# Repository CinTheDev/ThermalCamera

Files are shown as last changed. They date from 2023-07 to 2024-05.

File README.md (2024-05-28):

# Thermal Camera

A project for the Raspberry Pi, where a thermal camera is connected to the Raspi, which save or display pictures on a screen.

## Raspberry Pi image setup

### Initial setup

Following steps have been taken for the Raspberry Pi setup:

- Install Raspberry OS x32 on the SD card
- Setup install
- Country & Language: German
- Username: thermal-camera
- Password: thermal-camera
- Connect to WIFI
- Finish setup & Restart
- Enable ssh via systemctl

Now the Raspi can be accessed via `ssh thermal-camera@raspberrypi`

At this point, there is no need for an external keyboard and monitor anymore, the Raspi just needs to be powered and in reach of the configured WIFI.

Optional:

- Add personal public ssh key for easy access via ssh
- Install eog for viewing image files via ssh

### Peripheral setup

Later, when enabling the I2C peripheral:

- `sudo raspi-config`
- -> Interfacing Options
- -> I2C
- -> "Yes" to enable
- -> Finish

Restart so I2C can be activated.

Lastly, increase the speed of the I2C peripheral for images to be read much quicker:

- `sudo nano /boot/config.txt`
- Look for `dtparam=i2c_arm=on`
- Append `,i2c_arm_baudrate=400000` or whatever speed should be used
- Save

And restart again.

### Display setup

In order to use the display, some things still have to be configured.

<https://www.waveshare.com/wiki/3.5inch_RPi_LCD_(A)#Getting_Started>

Follow the first part of the guide with the driver installaion, skip the rest.

If the touchscreen axes are "inverted" in some way after reboot, you must edit `/usr/share/X11/xorg.conf.d/99-callibration.conf` and change "SwapAxes" to "0" (or to "1" if it's already 0)

Now the touchscreen should behave properly.

#### Increase Display framerate

If the default framerate is too slow:

- `sudo nano /boot/config.txt`
- Look for `dtoverlay=waveshare35a` and append `:speed=20000000,fps=30` or other desired values
- Save and restart

## Development setup

On our working machine, we have to make sure we can cross compile the program and upload it to the raspi.

We first have to add the correct Rust toolchain:

`rustup target add armv7-unknown-linux-gnueabihf`

We will use cargo cross for compiling. Install cross with `cargo install cross`

Additionally, we will use `podman` for cross, you can use docker instead, but it's kinda a chore to deal with root priviledges. Install podman with `sudo apt install podman`.

## Hardware setup & Used pins

### MLX Thermal Camera

The MLX module is connected to Raspberry Pi GPIO in the following fashion:

- [Camera Pin] > [Raspi Pin]
- VIN > 5V (Pin 2)
- GND > Ground (Any Pin equal or above Pin 30)
- SCL > Pin 3 (I2C SCL)
- SDA > Pin 2 (I2C SDA)

### Display Pins

Since some Pins are used by the MLX, we cannot put the Display directly on the Raspberry Pi, we have to manually connect the pins with jumper wires.

Also, the display, by documentation, occupies every power pin on the raspi. This is a problem since the MLX needs one power pin for itself. I have discovered that keeping **Pin 2 disconnected** won't affect the display. That way we have a free power pin for the MLX.

Use the display guide mentioned above in Display Setup to connect the relevant pins. The pins are listed on the bottom of the page.

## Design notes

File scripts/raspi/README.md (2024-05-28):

# Thermal Camera Raspberry Pi configuration

This directory contains scripts to fully configure a Raspberry Pi to run thermal-camera on startup

## Setup

Do the following before running any scripts inside here:

- Prepare a new Raspbian OS lite x32 sd card; if possible, do the following steps inside the raspberry pi imager
- **IMPORTANT: Do not choose anything newer than Raspbian Bullseye, display won't work otherwise!**
- (It's recommended to set the hostname to something other than raspberrypi)
- Make sure to create a user 'pi' with sudo rights; this will serve as the administrative user
- Connect to the internet either over wifi (recommended) or over ethernet
- (Turn on ssh)

## Installation

- Login as pi either over ssh or directly
- Copy this directory to /home/pi
- Set executable flag for run.sh
- Execute run.sh

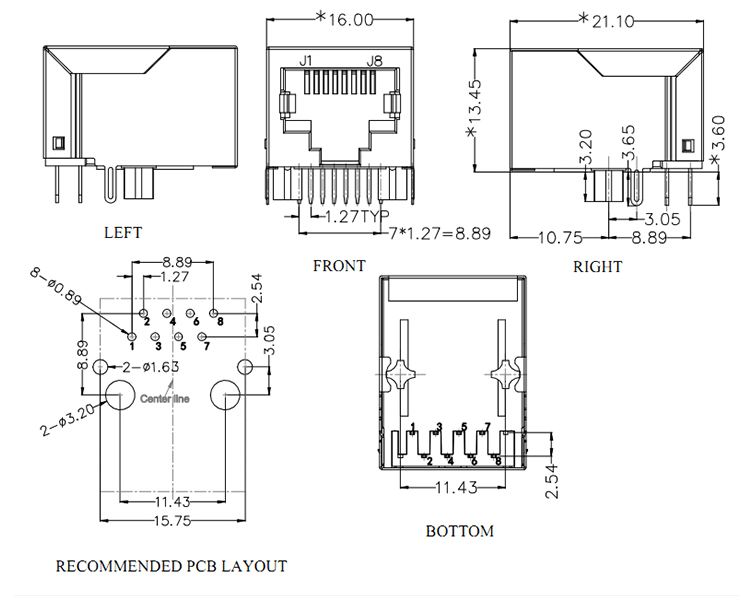
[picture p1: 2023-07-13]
Datasheets/Peripherals/Ethernet.png

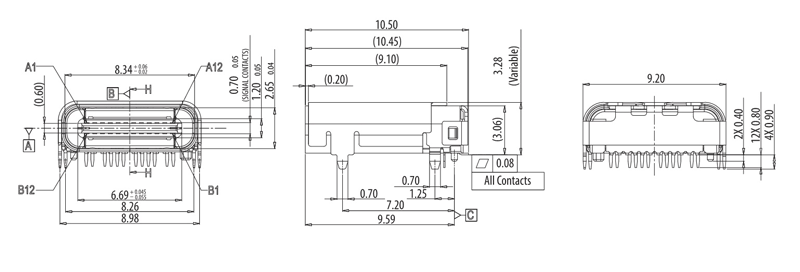
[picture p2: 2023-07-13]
Datasheets/Peripherals/USB_C_Female.png

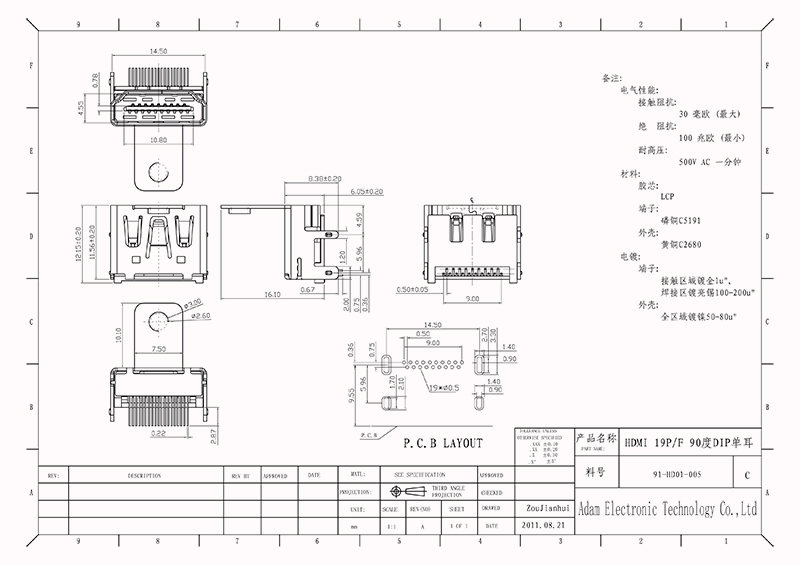
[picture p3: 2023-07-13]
Datasheets/Peripherals/HDMI_Mini_Female.jpg

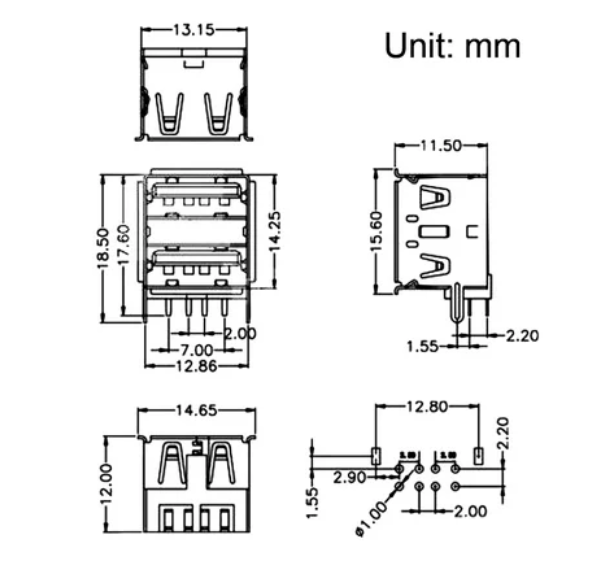
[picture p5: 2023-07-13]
Datasheets/Peripherals/USB_A_Female.png

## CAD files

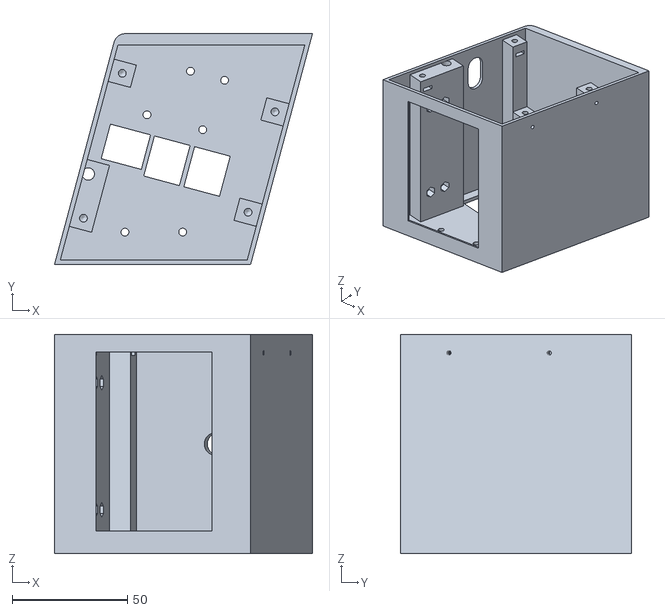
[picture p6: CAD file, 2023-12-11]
CAD_CaseV2/Export/Casing.stl
111.8 x 100.0 x 95.0

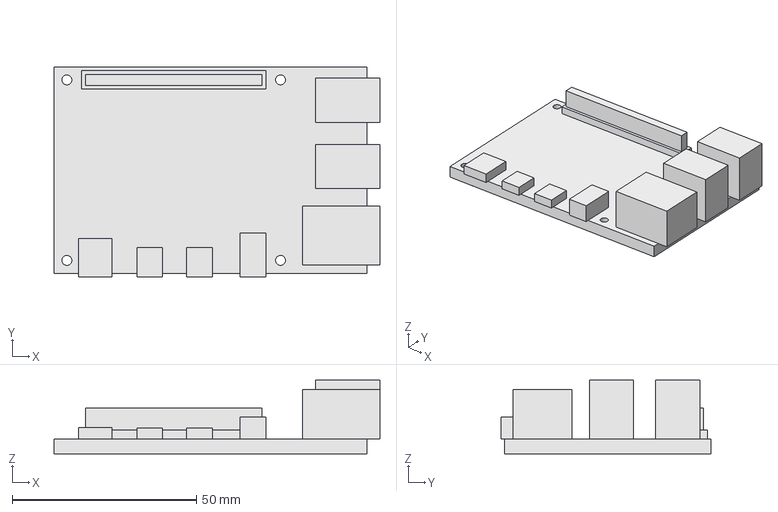
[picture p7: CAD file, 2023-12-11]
CAD_CaseV2/Parts/Raspberrypi4B.FCStd
88.5 x 57.0 x 20.0 mm

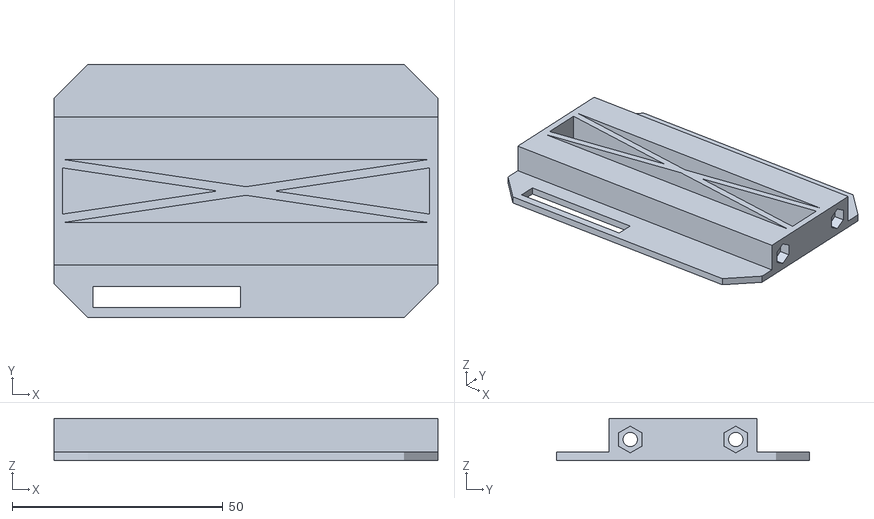
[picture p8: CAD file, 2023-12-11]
CAD_CaseV2/Export/Support_Display.stl
91.0 x 60.0 x 10.0

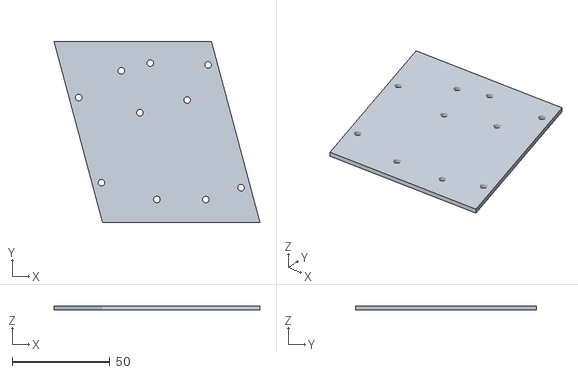
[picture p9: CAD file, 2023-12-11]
CAD_CaseV2/Export/Lid.stl
105.3 x 92.5 x 2.00

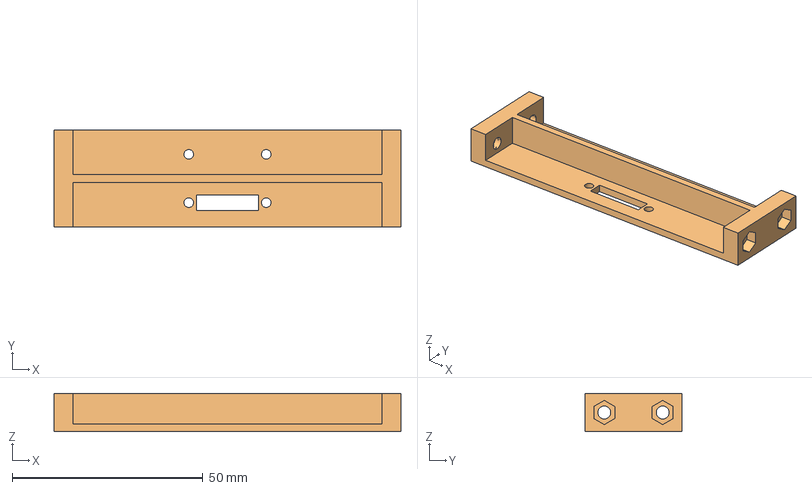
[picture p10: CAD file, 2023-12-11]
CAD_CaseV2/Parts/Support_MLX.FCStd
91.0 x 25.3 x 10.0 mm
Body (Meshed)

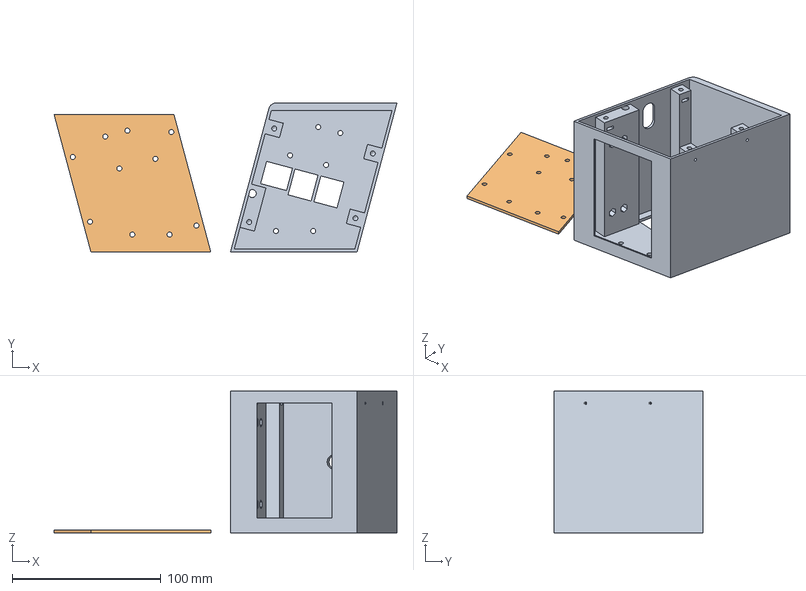
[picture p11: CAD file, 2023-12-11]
CAD_CaseV2/Export/CaseV2.3mf
230.3 x 100.1 x 95.0 mm
Casing.stl
Lid.stl

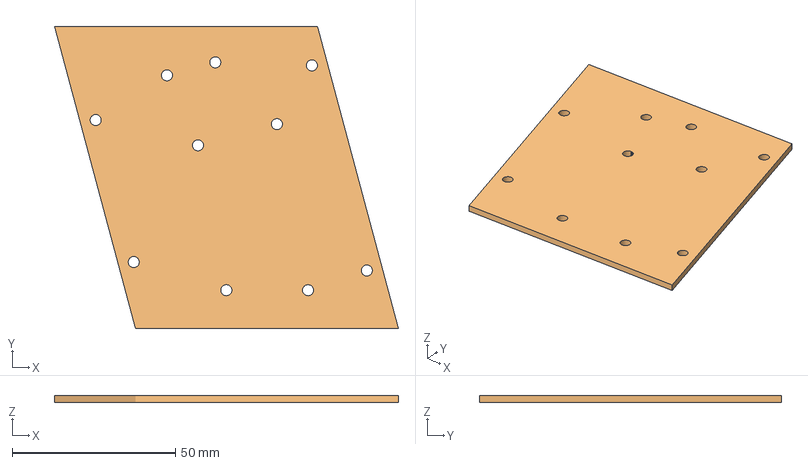
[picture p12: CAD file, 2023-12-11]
CAD_CaseV2/Parts/Casing_Lid_2.FCStd
105.3 x 92.5 x 2.00 mm
Körper
Körper (Meshed)

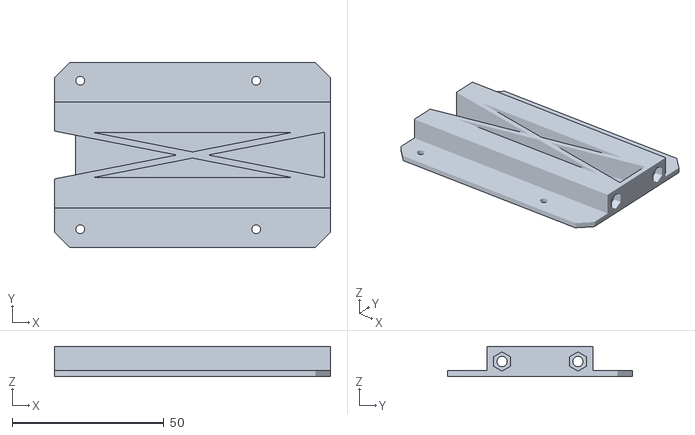
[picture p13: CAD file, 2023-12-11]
CAD_CaseV2/Export/Support_Raspi.stl
91.0 x 61.0 x 10.0

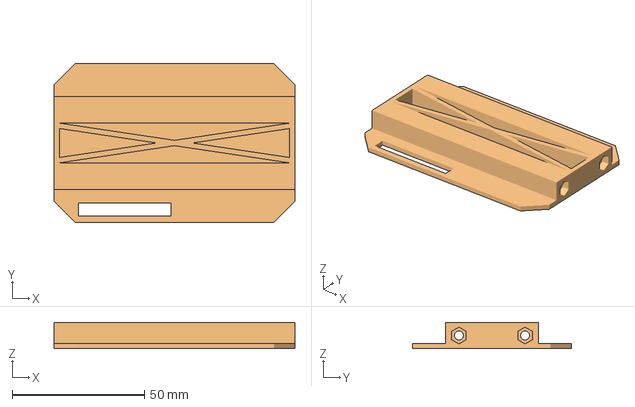
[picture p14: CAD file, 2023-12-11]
CAD_CaseV2/Parts/Support_Display_new.FCStd
91.0 x 60.0 x 10.0 mm
Körper
Körper (Meshed)

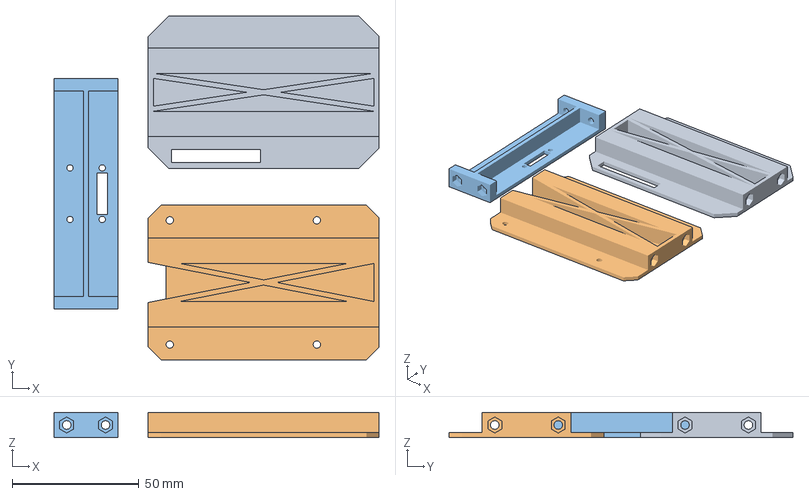
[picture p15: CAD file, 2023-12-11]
CAD_CaseV2/Export/Supports_V2.3mf
128.2 x 135.5 x 10.0 mm
Support_Display.stl
Support_Raspi.stl
Support_MLX.stl

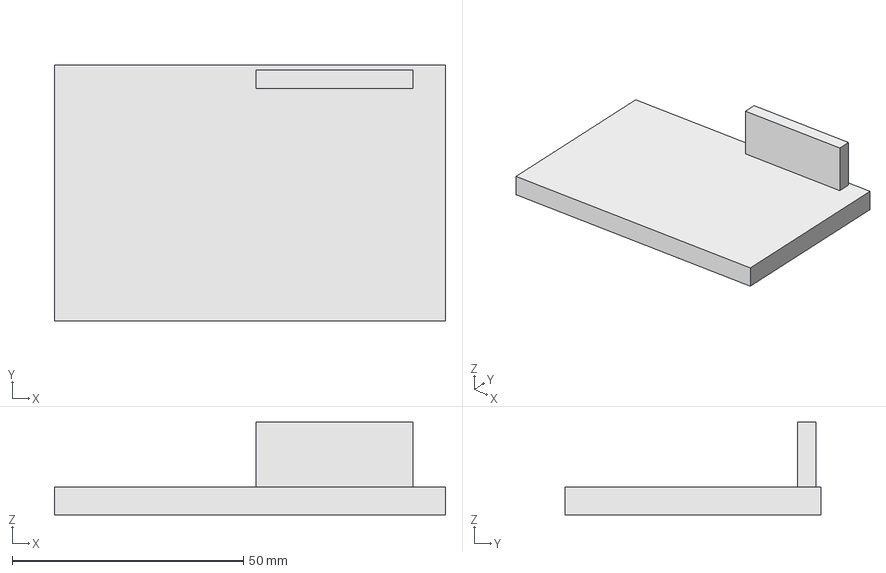
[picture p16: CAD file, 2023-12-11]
CAD_CaseV2/Parts/Display_Berrybase.FCStd
84.5 x 55.3 x 20.0 mm

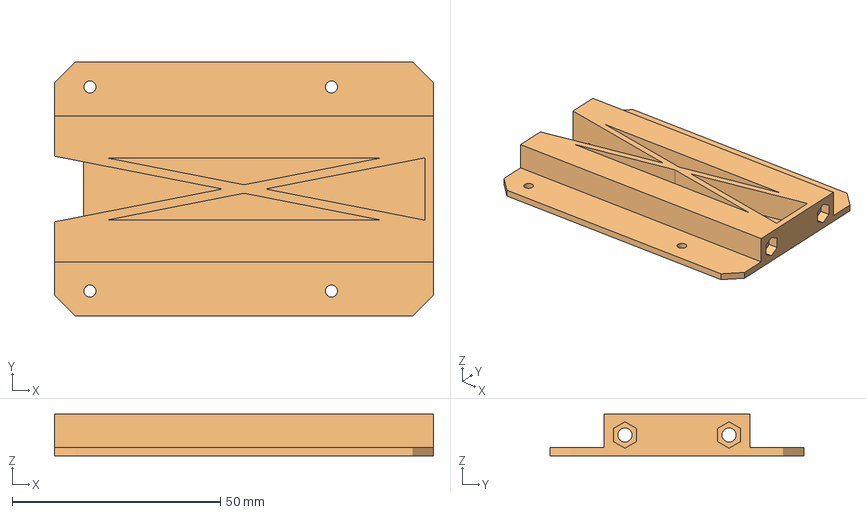
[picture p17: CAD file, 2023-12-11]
CAD_CaseV2/Parts/Support_Raspi_new.FCStd
91.0 x 61.0 x 10.0 mm
Körper
Körper (Meshed)

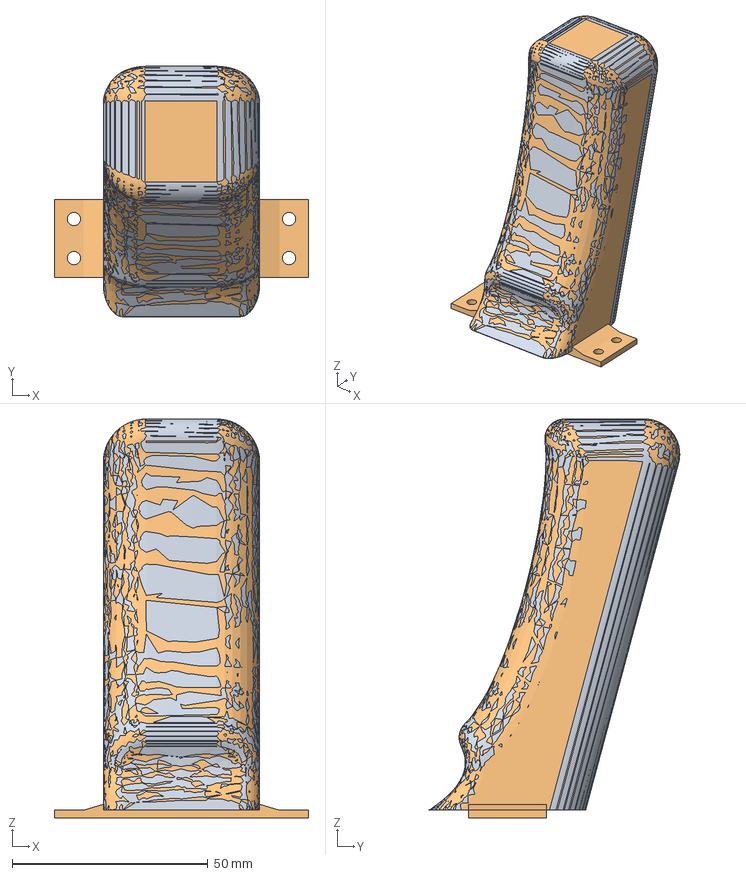
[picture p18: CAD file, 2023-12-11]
CAD_CaseV2/Parts/Handgrip.FCStd
65.0 x 64.1 x 102.0 mm
Körper
Körper (Meshed)

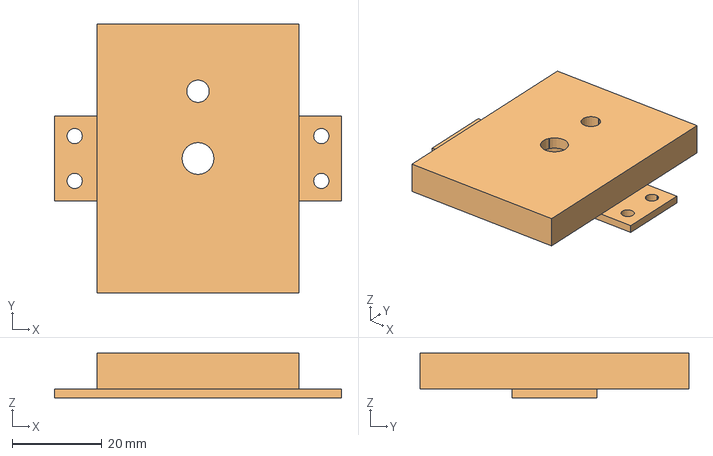
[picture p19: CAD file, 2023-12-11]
CAD_CaseV2/Parts/Tripod_Connector.FCStd
64.0 x 60.0 x 10.0 mm
Körper
Körper (Meshed)

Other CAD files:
CAD_CaseV2/CaseV2_Assembly.FCStd
CAD_CaseV2/Parts/Casing2.FCStd
CAD_CaseV2/Parts/MLX90640.FCStd
CAD_CaseV2/Export/Handgrip.3mf
CAD_CaseV2/Export/Handgrip.stl
CAD_CaseV2/Export/Support_MLX.stl
CAD_CaseV2/Export/Tripod_Connector.3mf
CAD_CaseV2/Export/Tripod_Connector.stl

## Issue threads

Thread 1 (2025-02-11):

Equivalent to set i2c frequency like  busio.I2C(board.SCL, board.SDA, frequency=frequency)

UlmerMan, 2025-02-11:
Description:

I'm looking for a way to set the I2C frequency in this crate, similar to how it can be done in CircuitPython using busio.I2C with the frequency parameter, like this:

```
import board
import busio

i2c = busio.I2C(board.SCL, board.SDA, frequency=100_000)
```

In particular, I'd like to know:

 -   Is there a way to specify the I2C frequency directly when initializing the I2C bus?

It would be helpful for applications where controlling the bus speed is essential (e.g., for devices with stricter timing requirements).

CinTheDev, 2025-02-11:
Unfortunately, there's no way right now to do this software wise. The crate uses `rppal` for utilizing the raspi I2C hardware.

Though, you can change the raspi configuration in `/boot/firmware/config.txt` to adjust the speed. The rppal documentation says the same:

> By default, the I2C bus clock speed is set to 100 kHz. Transferring 1 bit takes 1 clock cycle. You can change the transfer rate by adding dtparam=i2c_arm_baudrate=X to /boot/firmware/config.txt, where X should be replaced with the clock frequency in hertz (Hz). Remember to reboot the Raspberry Pi afterwards.

So, in your example you would add `dtparam=i2c_arm_baudrate=100000` to `/boot/firmware/config.txt`. (If it's there already, edit it)

UlmerMan, 2025-02-12:
Thank you for the fast answer and your amazing work

Closed 2025-02-12.

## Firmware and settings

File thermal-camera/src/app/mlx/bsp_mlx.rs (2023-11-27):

use rppal::i2c::I2c;
use std::sync::Mutex;
use lazy_static::lazy_static;

mod mlx_eeprom;

use super::PIXEL_COUNT;

const CAM_ADDR: u8 = 0x33;

pub const REGISTER_STATUS: u16 = 0x8000;
pub const REGISTER_CTRL: u16 = 0x800D;
pub const ADDRESS_RAM: u16 = 0x0400;

lazy_static! {
    static ref I2C_MUTEX: Mutex<u32> = Mutex::new(0);
}

pub fn write(address: u16, data: u16) -> Result<(), String> {
    let _i2c_lock = I2C_MUTEX.lock().unwrap();

    let i2c_p_response = I2c::new();

    if i2c_p_response.is_err() {
        return Err(format!("I2C Peripheral failure\n{}", i2c_p_response.unwrap_err()));
    }

    let mut i2c = i2c_p_response.unwrap();
    i2c.set_slave_address(CAM_ADDR as u16).unwrap();

    let mut buffer: [u8; 4] = [0x00; 4];
    buffer[0..2].copy_from_slice(&address.to_be_bytes());
    buffer[2..4].copy_from_slice(&data.to_be_bytes());
    
    let i2c_write_response = i2c.write(&buffer);
    if i2c_write_response.is_err() {
        return Err(format!("I2C Write failure\n{}", i2c_write_response.unwrap_err()));
    }

    return Ok(());
}

pub fn read(address: u16, read_buffer: &mut [u8]) -> Result<(), String> {
    let _i2c_lock = I2C_MUTEX.lock().unwrap();

    let i2c_p_response = I2c::new();

    if i2c_p_response.is_err() {
        return Err(format!("I2C Peripheral failure\n{}", i2c_p_response.unwrap_err()));
    }

    let mut i2c = i2c_p_response.unwrap();
    i2c.set_slave_address(CAM_ADDR as u16).unwrap();

    let mut write_buffer: [u8; 2] = [0x00; 2];
    write_buffer.copy_from_slice(&address.to_be_bytes());

    let i2c_read_response = i2c.write_read(&write_buffer, read_buffer);
    if i2c_read_response.is_err() {
        return Err(format!("I2C Read failure\n{}", i2c_read_response.unwrap_err()));
    }

    return Ok(());
}

pub fn read_value(address: u16) -> Result<u16, String> {
    let mut read_buffer: [u8; 2] = [0x00; 2];
    let read_response = read(address, &mut read_buffer);

    if read_response.is_err() {
        return Err(read_response.unwrap_err());
    }

    return Ok(u16::from_be_bytes(read_buffer));
}

pub fn evaluate_image(pix_data: [u16; PIXEL_COUNT]) -> Result<[f32; PIXEL_COUNT], String> {
    return mlx_eeprom::evaluate(pix_data);
}

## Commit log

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2023-05-10 Fully replace old i2c code
    [bsp_mlx.rs]
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2023-05-11 Replace eeprom_raw with whole data block
    [bsp_mlx.rs]
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2023-05-14 Fix all mistakes and save temperature output
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2023-05-24 Fix t clamping
2023-06-02 Change target because of linking issues
    Currently the rust compiler is complaining about failed linking,
    and if it does succeed the program won't run on the raspy because of issues with glibc.
    I'll look into that now.
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2023-06-21 Add new FreeCAD project
    [Case_Assembly.FCStd]
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2023-06-21 Create base of Raspberrypi model
    [Raspberrypi4B.FCStd]
2023-06-21 Make spreadsheet and replace most numbers
    [Case_Assembly.FCStd, Raspberrypi4B.FCStd]
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2023-06-21 Replace raspi spreadsheet expressions
    Replace all Case_Assembly#Spreadsheet... with <<Case_Assembly>>#<<Spreadheet>>...
    [Raspberrypi4B.FCStd]
2023-06-21 Update mlx pcb factor to represent an inch
    [Case_Assembly.FCStd, MLX90640.FCStd, Raspberrypi4B.FCStd]
2023-06-26 Add berrybase display CAD and empty Casing left file
    [Case_Assembly.FCStd, Casing_Left.FCStd, Display_Berrybase.FCStd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]
2023-06-26 Add basic shape for casing
    [Casing_Left.FCStd]
2023-06-26 Create rough outline of casing fron side
    [Casing_Left.FCStd]
2023-06-26 Add bspline for handgrip
    [Casing_Left.FCStd]
2023-06-26 Convert all units to mm
    [Case_Assembly.FCStd, Casing_Left.FCStd, Display_Berrybase.FCStd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]
2023-06-26 Add second depth for bspline
    [Casing_Left.FCStd]
2023-06-26 Edit main case shape end remove first sketch
    [Casing_Left.FCStd]
2023-06-26 Pocket the handgrip into shape
    [Casing_Left.FCStd]
2023-06-26 Add basic pocket to hollow out casing
    [Casing_Left.FCStd]
2023-06-27 Remove Casing_left, Replace with Casing_middle
    [Casing_Left.FCStd, Casing_Middle.FCStd]
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2023-06-27 Add hole in casing for mlx camera
    [Casing_Left.FCStd, Casing_Middle.FCStd]
2023-06-28 Add Casing_Right as well
    [Casing_Left.FCStd, Casing_Right.FCStd]
2023-06-28 Fix Casing_Left orientation
    [Casing_Left.FCStd]
2023-06-28 Start adding beams to Casing_Left
    [Casing_Left.FCStd, Casing_Middle.FCStd, Casing_Right.FCStd]
2023-06-28 Move mlx spreadsheet values to mlx file
    [Case_Assembly.FCStd, MLX90640.FCStd]
2023-06-28 Add Case_Middle to main assembly
    [Case_Assembly.FCStd, Casing_Middle.FCStd, MLX90640.FCStd]
2023-06-28 Add more beams to Casing_left
    [Case_Assembly.FCStd, Casing_Left.FCStd, Casing_Middle.FCStd]
2023-06-28 Add screwholes to casing_left
    [Casing_Left.FCStd]
2023-06-28 Add screwholes to Casing_Middle and add Casing_Left to assembly
    [Case_Assembly.FCStd, Casing_Left.FCStd, Casing_Middle.FCStd]
2023-06-28 Fix various errors which popped up
    [Case_Assembly.FCStd, Casing_Left.FCStd]
2023-06-28 Shorten beam length to correct size
    [Case_Assembly.FCStd, Casing_Left.FCStd]
2023-06-28 Fix Casing_Left
    [Case_Assembly.FCStd, Casing_Left.FCStd, Casing_Middle.FCStd]
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2023-06-30 Add carrier beam for mlx
    [Case_Assembly.FCStd, Casing_Left.FCStd, Casing_Middle.FCStd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]
2023-06-30 Add mlx carrier to main assembly
    [Case_Assembly.FCStd, Casing_Left.FCStd, Casing_Middle.FCStd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]
2023-06-30 Add mlx camera to main assembly
    [Case_Assembly.FCStd, Casing_Left.FCStd, Casing_Middle.FCStd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]
2023-06-30 Add holes to Case_Right as well
    [Case_Assembly.FCStd, Casing_Left.FCStd, Casing_Middle.FCStd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]
2023-07-03 Add own spreadsheets to Raspberrypi4B and Display_Berrybase
    [Case_Assembly.FCStd, Casing_Left.FCStd, Casing_Right.FCStd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]
2023-07-03 Replace raspi fixed lengths with spreadsheet values
    [Raspberrypi4B.FCStd]
2023-07-03 Add carrier for raspberrypi
    [Raspberrypi4B.FCStd, Support_Raspi.FCStd]
2023-07-03 Add holes to Casing_Left
    [Case_Assembly.FCStd, Casing_Left.FCStd, Casing_Middle.FCStd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]
2023-07-03 Resize Case height to fit Raspi carrier
    [Case_Assembly.FCStd, Casing_Left.FCStd, Casing_Middle.FCStd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]
2023-07-03 Add holes to Casing_Right
    [Case_Assembly.FCStd, Casing_Left.FCStd, Casing_Right.FCStd]
2023-07-03 Add Support_Raspi to assembly
    [Case_Assembly.FCStd, Casing_Left.FCStd, Casing_Right.FCStd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]
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2023-07-05 Fix alignment issues
    [Case_Assembly.FCStd, Casing_Left.FCStd, Casing_Middle.FCStd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]
2023-07-05 Resketch Casing_Middle for more clean geometry and sketches
    [Case_Assembly.FCStd, Casing_Left.FCStd, Casing_Middle.FCStd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]
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2023-07-05 Fix alignment of display guard
    [Case_Assembly.FCStd, Casing_Left.FCStd, Casing_Middle.FCStd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]
2023-07-05 Place display a little further back for guards
    [Case_Assembly.FCStd, Casing_Left.FCStd, Casing_Middle.FCStd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]
2023-07-06 Fix MLX camera hole in Casing_Middle
    [Case_Assembly.FCStd, Casing_Middle.FCStd]
2023-07-06 Add hole to Casing_Left for USB C access
    [Case_Assembly.FCStd, Casing_Left.FCStd, Casing_Right.FCStd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]
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2023-07-08 Make holes for Raspberrypi USB and Ethernet in Casing_Right
    [Case_Assembly.FCStd, Casing_Right.FCStd]
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2023-07-19 Replace mlx carrier middle beam with side beams
    [Case_Assembly.FCStd, Casing_Left.FCStd, Casing_Middle.FCStd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]
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2023-07-19 Revert back to old mlx carrier design
    [Case_Assembly.FCStd, Casing_Left.FCStd, Support_MLX.FCStd]
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2023-07-19 Add slicer project files
    These files belong to Prusa Slicer
    [Casing.3mf, Supports.3mf]
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2023-07-21 Update Casing parts and assembly for new carrier design
    [Case_Assembly.FCStd, Casing_Left.FCStd, Casing_Right.FCStd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]
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2023-08-16 Update Casing_Right in the same way as Casing_Left
    [Case_Assembly.FCStd, Casing_Left.FCStd, Casing_Right.FCStd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]
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2023-08-16 Make room for 6 point nuts in Support_MLX
    [Case_Assembly.FCStd, Casing_Left.FCStd, Casing_Right.FCStd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]
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2023-08-16 Fix nut size in all parts
    [Case_Assembly.FCStd, Casing_Left.FCStd, Casing_Middle.FCStd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]
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2023-08-16 Change Support_Raspi design to be similar like Support_Display
    [Case_Assembly.FCStd, Casing_Left.FCStd, Casing_Right.FCStd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]
2023-08-16 Reduce display clearance
    [Case_Assembly.FCStd, Casing_Left.FCStd, Casing_Middle.FCStd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]
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2023-09-10 Fix part file links in FreeCAD
    [CaseV2_Assembly.FCStd, Case_Assembly.FCStd, Casing.FCStd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]
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2023-09-10 Fix Casing height
    [CaseV2_Assembly.FCStd, Case_Assembly.FCStd, Casing.FCStd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]
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2023-10-07 Add space for square nuts to be inserted
    [CaseV2_Assembly.FCStd, Casing.FCStd]
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2023-10-08 Add clearance to handgrip base
    [CaseV2_Assembly.FCStd, Handgrip.FCStd]
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2023-10-16 Attempt to place buttons with allocate_space() [failed]
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2023-10-20 Adjust wrongly placed screw hole
    [CaseV2_Assembly.FCStd, Casing_Top.FCStd]
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2023-10-20 Fix mlx space
    [CaseV2_Assembly.FCStd, Casing.FCStd, Casing_Top.FCStd]
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2023-10-21 Add button to revert color algorithm back to hue
2023-10-21 Fix bug where after changing color, the change would apply two frames after
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2023-10-21 Correct USB power hole position
    Somehow my last correction yesterday made the position worse, now the cable won't fit.
    [CaseV2_Assembly.FCStd, Casing.FCStd]
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2023-10-22 Correct button enabling
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2023-10-29 Add cross beam pattern to new display support
    [Support_Display.FCStd, Support_Display_new.FCStd]
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2023-10-29 Replace display support with new design
    [CaseV2_Assembly.FCStd, Casing2.FCStd, Casing_Lid_2.FCStd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]
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2023-10-29 Replace raspi support with new one
    [CaseV2_Assembly.FCStd, Support_Raspi_new.FCStd]
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2023-10-29 Combine lower front beam and extra beam into one
    [Casing2.FCStd]
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2023-10-29 Remove clearance from handgrip
    [CaseV2_Assembly.FCStd, Casing2.FCStd, Handgrip.FCStd]
2023-10-29 Reduce tolerance on interface
    [CaseV2_Assembly.FCStd, Casing2.FCStd, Handgrip.FCStd]
2023-10-29 Reduce tolerance on lid
    [CaseV2_Assembly.FCStd, Casing_Lid_2.FCStd]
2023-10-29 Add small chamfer to handgrip for stability
    [CaseV2_Assembly.FCStd, Handgrip.FCStd]
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2023-10-29 Remove mlx support from slicer as it's already printed
    [Supports_V2.3mf]
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2023-10-30 Rotate mlx mount points to point carrier forward
    [CaseV2_Assembly.FCStd, Casing2.FCStd]
2023-10-30 Adjust mlx thickness to account for extra parts on PCB
    [CaseV2_Assembly.FCStd, Casing2.FCStd, MLX90640.FCStd]
2023-10-30 Update sizes in mlx carrier to account for rotation
    [CaseV2_Assembly.FCStd, Casing2.FCStd]
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2023-10-30 Add small openings to make removing square nuts easier
    [CaseV2_Assembly.FCStd, Casing2.FCStd, Casing_Lid_2.FCStd]
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2023-11-02 Add small correction to make display drivers install correctly
2023-11-02 Successfully prevent display drivers from restarting entire system
2023-11-02 Replace fbturbo config file with calibration config file
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2023-11-05 Reenable i2c and check for errors
    [bsp_mlx.rs]
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2023-11-05 Add error message forwarding from mount
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2023-11-12 Use correct stl file
    [Tripod_Connector.3mf]
2023-11-12 Use Error Responses in bsp_mlx::read_value()
    [bsp_mlx.rs]
2023-11-12 Do not print failure when waiting
2023-11-12 Make thread sleep a bit on error
2023-11-12 Include rrpal error message in bsp_mlx error messages
    [bsp_mlx.rs]
2023-11-19 Fix i2c configuration
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2023-11-22 Add pocket in raspi support for better sd access
    [CaseV2_Assembly.FCStd, Casing2.FCStd, Support_Raspi_new.FCStd]
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2023-11-22 Fix LCS_interface
    [Casing2.FCStd]
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2023-11-25 Fix left mouse button problem
    When pressing holding on a specific point, the display sends a right click instead of a left click.
    In order to fix this, listen to all mouse buttons instead of just left (primary button).
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
